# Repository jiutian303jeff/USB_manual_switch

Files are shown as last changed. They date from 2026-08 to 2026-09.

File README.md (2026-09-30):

# USB-A Physical Isolation Switch
---

## 📢 Current Update 
## (August 30, 2026)
### Overview & current update link: https://docs.google.com/document/d/1pLDk2mAq172Uoo87mN2TMu-KEBSsqmwrNO6xUET-iXo/edit?usp=drive_link

**Ver 2.0 Final Fabrication Release & Design Freeze**
* **TVS ESD Protection Integration**: Integrated an industrial-grade **SRV05-4** TVS diode array to clamp electrostatic discharge and voltage spikes during hot-plugging.
* ** D+/D-  Signal Tuning**: Executed single-track serpentine length tuning on differential signal traces to optimize USB 2.0 signal integrity.
* **100% Single-Sided Top Placement**: Re-engineered component placement, consolidating all connectors, switches, TVS ICs, and LEDs onto the Top Layer F.Cu for an improved visual aesthetic and lower-cost single-sided SMT reflow.
* **Ground Copper Pour**: Replaced thin discrete ground tracks with continuous Top and Bottom Ground Planes to minimize impedance and lower EMI.
* **Manufacturing Package**: All production Gerber files, drill files have been verified via KiCAD DRC (0 Errors) and packaged for fabrication.

---

##  Product Overview

The **USB-A Physical Isolation Switch** is an air-gapped hardware security and power management device designed in KiCAD 9.0. Unlike software-based toggles that rely on OS drivers and remain vulnerable to remote exploits, this hardware module provides a physical "hard-cut" for USB-connected peripherals. It ensures absolute data privacy, prevents unauthorized data exfiltration, and offers convenient hardware resetting without the mechanical wear of repeated plugging/unplugging.

note: content will change over time based on latest updates

---

##  Key Features

* **Air-Gapped Privacy & Security**: Physical DPDT switch physically breaks  V_{BUS}  power and  D+  data lines for 100% reliable hardware-level isolation.
* **Sub-Nanosecond ESD Protection**: Integrated **SRV05-4** TVS diode array clamps voltage transients across  V_{BUS} ,  D+ , and  D-  lines.
* **Matched Differential Pair ( 0.00\text{ mm}  Skew)**: Serpentine length tuning compensates for trace length differences caused by switch cutouts, maintaining data integrity.
* **Single-Sided SMT Layout**: Unified component layout on the top side simplifies assembly and provides a clean, professional finish.
* **Solid Grounding & EMI Reduction**: Continuous Ground Copper Pour (GND Zone) on both layers reduces ground loop impedance and improves heat dissipation.
* **Dual-LED Status Indication**:
  * 🟢 **Green LED ( ON\_GREEN )**: Active connection ( V_BUS  and data lines fully connected).
  * 🔴 **Red LED ( OFF\_RED )**: Isolated/OFF state ( V_BUS  disconnected from downstream port, routing through a  220,mega  resistor).

---

## 📁 File content

```text
.
├── final.zip                            # Complete manufacturing package (All Gerbers, Drill files etc)
├── USB-A switch overview.pdf            # Initial Ver 1.0 baseline documentation & overall project concept https://docs.google.com/document/d/1pLDk2mAq172Uoo87mN2TMu-KEBSsqmwrNO6xUET-iXo/edit?usp=drive_link
├── USB-A switch ver-xx.xx_update.pdf    # Updating report detailing new elements, technical iteration & design rationale https://docs.google.com/document/d/1X9TlPd9sVfkH2GCSMDSQgF4tiR_iDZ1_ytxDP3pgHG8/edit?usp=sharing
├── new_KiCAD_thing.kicad_pcb            # KiCAD PCB layout source file
├── new_KiCAD_thing.kicad_sch            # KiCAD schematic source file
├── PCB.png                              # High-resolution PCB Layout diagram preview
├── Schematic.png                        # High-resolution Schematic diagram preview
└── README.md                            # Project documentation
```

## 👤 Author & Acknowledgments

* **Author**: Haoyang Jiang
* **Date**: August 30, 2026
* **Designed With**: KiCAD EDA 9.0

---

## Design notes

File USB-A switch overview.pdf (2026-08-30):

# USB-A Manual Switch Ver 1.0

### A Physical USB Switch

Project Report | 2026 | Haoyang Jiang

## 1. Project Overview

The primary goal of this project was to

design and prototype a custom USB-A

Manual Power Switch. This hardware

module provides a physical "hard-cut" for

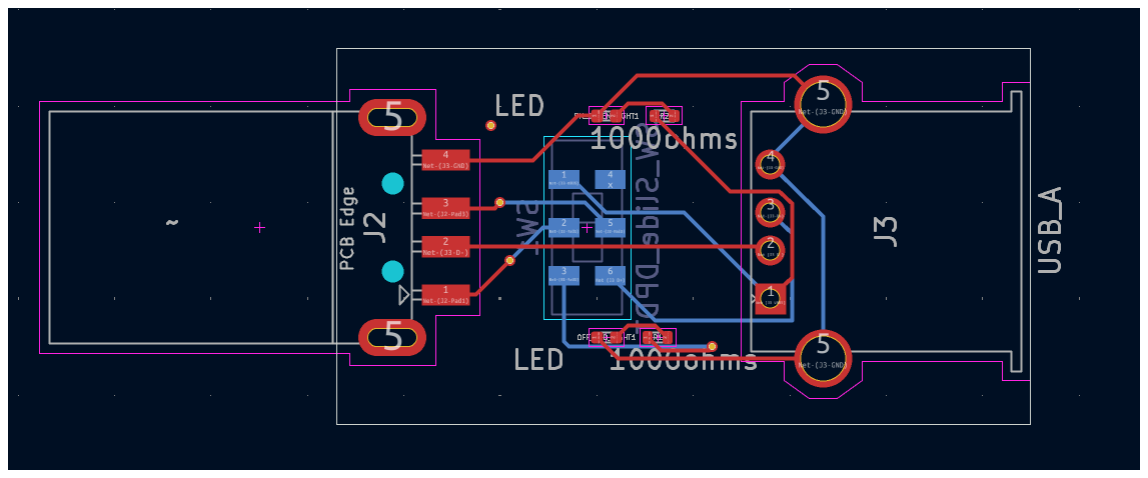
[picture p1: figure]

USB-connected peripherals, addressing the need for enhanced privacy and convenient

hardware resetting without the wear and tear of frequent plugging/unplugging.

### Technical Scope

The development process involved a full-cycle Electronic Design Automation (EDA)

workflow, encompassing:

- Schematic Capture: Designing the electrical logic and selecting appropriate components (USB

connectors, LED indicators, and slide switches).

- PCB Layout: Translating the logic into a physical 2-layer board design using KiCAD 9.0.
- Mechanical Constraint Management: Managing height interference between high-profile USB

connectors and low-profile switches.

### Key Features

- Mixed-Signal Integration: Successfully

integrated Surface Mount Device (SMD)

components for space-saving and

Through-Hole Technology (THT)

components for mechanical structural

integrity.

- Optimized 3-D Routing: Utilized multi-layer

routing strategies and via-interconnections to

achieve a compact footprint.

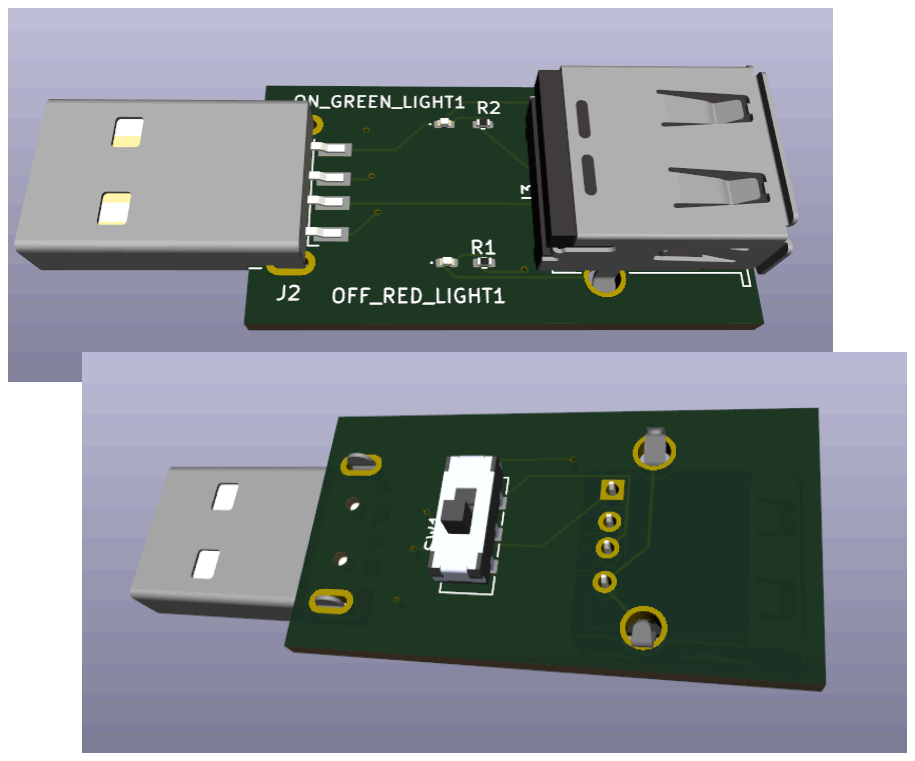
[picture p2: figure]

- Manufacturing Ready: The final design passed all Design Rule Checks (DRC), meeting

industrial standards for trace clearance, silk-screen alignment, and board edge integrity.

## 2. Social and Practical Value

### A. Absolute Security through Physical Disconnection

Unlike software-based toggles (which rely on the integrity of the Operating System and drivers), a

physical switch provides an "Air-gapped" level of security.

- Unhackable Nature: Since the switch physically breaks the VCC (5V) or Data lines, no

malware or remote exploit can bypass the hardware state. This is the only 100% reliable

method to prevent unauthorized data exfiltration or peripheral hijacking.

### B. Psychology of Control: The "Sense of Agency"

Research in human-computer interaction suggests that users feel a significantly higher sense of

agency (the feeling of being in control of one’s actions and their effects) when using mechanical

interfaces compared to digital ones.

- Visibility vs. Obscurity: A software icon can be spoofed or fail to update due to a system lag.

A physical switch provides a permanent, visible state that requires no "trust" in the

software—the user can see and feel the disconnected state.

- The "Locus of Control": Moving the privacy control from the "System" (External Locus) to

the "User's hand" (Internal Locus) reduces "techno-anxiety." Users no longer need to wonder,

"Is the light really of because the camera is of , or because the hacker disabled the LED?"

### C. Tactile Feedback and Closure (Psychological Satisfaction)

The use of a mechanical slide switch taps into the psychology of Haptic Feedback:

- Sensory Confirmation: The "click" or resistance of a physical switch provides immediate

auditory and tactile confirmation. This sensory loop creates a psychological "Sense of

Closure," delivering a level of satisfaction and "peace of mind" that a silent mouse click on a

screen cannot replicate.

- Ritualistic Security: For high-stakes environments (e.g., sensitive meetings), the act of

physically flicking a switch becomes a "security ritual" that reinforces the user’s confidence

in their environment's privacy.

## 3. Challenges and Engineering Solutions

### Challenge A: Vertical Geometric Interference

- The Problem: The standard USB-A Female connector (J3) has a significant vertical profile

(approx. 7mm). When placed on the same side as the Slide Switch (SW1), the connector's

casing physically obstructed finger access to the switch, making the device nearly impossible

to operate.

- Engineering Solution: Implemented a Bottom-Layer Component Strategy. By flipping the

switch to the Bottom Copper Layer (B.Cu) while keeping the connectors on the Top Layer

(F.Cu), I utilized the PCB substrate as a physical separator. This maximized ergonomic

accessibility without increasing the PCB's X-Y footprint.

### Challenge B: Cross-Layer Electrical Connectivity

- The Problem: Shifting the switch to the bottom layer disconnected it from the main 5V power

bus on the top layer. I needed a way to route high-current power through the board without

compromising signal integrity.

- Engineering Solution: I utilized Vias (Vertical Interconnect Access) to create "electrical

bridges."

- I routed the 5V input to a Via on the top layer, transitioned the signal to the bottom

layer to interface with the switch, and then used another Via to bring the switched

power back to the top-layer output.

- Trace Width Optimization: To handle up to 2A of current, I increased the power trace

width to 0.5mm, ensuring low resistance and preventing overheating.

### Challenge C: Mechanical Durability & Stress Management

- The Problem: USB ports are subject to frequent insertion and withdrawal forces, which can

easily snap the solder joints of Surface Mount (SMD) connectors.

- Engineering Solution: I opted for Through-Hole Technology (THT) for the USB-A

connectors. The THT pins penetrate the entire PCB and are soldered on both sides, providing superior mechanical anchorage compared to SMD pads. This ensures the device can

withstand long-term physical stress.

### Challenge D: Design Rule Constraint (DRC) Violations

- The Problem: During the final verification, the KiCAD DRC engine flagged "Silkscreen

clipped by board edge" and "Malformed board outline" errors.

- Engineering Solution: * I performed a manual audit of the Edge.Cuts layer to ensure a

perfectly closed-loop polygon.

- I resolved the silkscreen warnings by modifying the J2 footprint, trimming the

non-essential legend lines that extended beyond the manufacturing boundary. This

ensured a clean, professional finish without any "bleeding" of ink during the

fabrication process.

## 4. Technical Summary

This section summarizes the technical specifications and design standards achieved in the

final version of the PCB.

### PCB Specifications

- Board Type: Dual-layer Rigid PCB (FR-4 Substrate).
- Dimensions: Compact form factor designed for portable USB integration.
- Copper Weight: 1 oz/ft² (Standard for stable power delivery).
- Surface Finish: HASL (Hot Air Solder Leveling) with Lead-Free compatibility.

### Electrical Parameters

- Operating Voltage: 5.0V DC (Standard USB Bus Voltage).
- Current Capacity: Rated for up to 2.0A, supported by 0.5mm power traces to minimize

voltage drop and thermal buildup.

- Signal Integrity: Maintains direct data line continuity (D+/D-) for peripheral recognition

while switching the VCC line.

### Design Compliance (DRC Results)

The design was validated against industrial manufacturing constraints using the KiCAD 8.0

Design Rule Checker:

- Critical Errors: 0
- Unconnected Items: 0
- Minimum Clearance: 0.2 mm (Ensures no short circuits during fabrication).
- Minimum Trace Width: 0.25 mm (Signal) / 0.5 mm (Power).

## Schematic Overview:

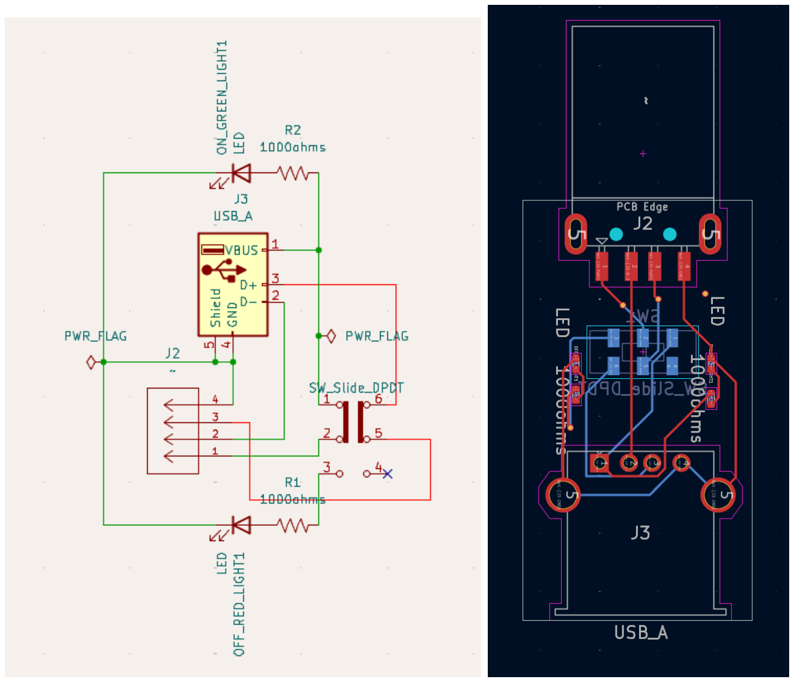
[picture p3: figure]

## 5. Relevance to Engineering Study

This project served as a practical bridge between high school theoretical physics and applied

engineering, reinforcing several core competencies required for undergraduate success:

### A. Application of Theoretical Physics

The design process required a deep understanding of Ohm’s Law and Thermal Dynamics.

Calculating the necessary trace width to support 2A of current without excessive heat

generation transformed an abstract classroom formula into a critical design constraint. This

reinforced the importance of using mathematical models to predict hardware behavior before

fabrication.

### B. Systems Thinking and Spatial Reasoning

Working in a 3D CAD environment (KiCAD) demanded advanced spatial reasoning. Solving

the interference between the USB-A housing and the switch through Bottom-Layer

Implementation taught me how to view a system as a 3D entity rather than a 2D drawing. This

aligns with the "Systems Thinking" approach central to Mechatronics and Electrical

Engineering.

### C. The Iterative Design Cycle

The transition from a "Malformed Outline" error to a "0 Error / 0 Warning" state exemplified

the Engineering Design Process (EDP). I learned that engineering is rarely about getting it

right the first time; it is about systematic debugging, interpreting technical documentation,

and iterating until the design meets all safety and manufacturing constraints.

### D. Attention to Detail and Documentation

The rigorous requirement for DRC (Design Rule Check) compliance taught me that precision

is paramount. A single 0.2mm clearance violation could lead to a short circuit and project

failure. This project cultivated a disciplined approach to technical documentation and

rule-following that is essential for professional engineering practice.

## 6. Conclusion & Future Work

This project successfully demonstrates the feasibility of a high-current, compact USB power

switch designed through advanced PCB routing techniques. By navigating complex 3-D

spatial constraints and adhering to rigorous manufacturing standards, I have developed a

hardware solution that bridges the gap between digital privacy needs and physical

ergonomics. The successful elimination of all DRC errors confirms that the design is ready

for industrial fabrication and practical deployment.

### Future Work

While the current version (v1.0) achieves its core functional goals, I intend to further iterate on the

design in the following areas:

- Enclosure Integration: I plan to export the PCB as a STEP model and utilize Fusion 360 for

collaborative mechanical design. This will involve creating a custom-fit, 3D-printed enclosure

with integrated mounting bosses and precise port cutouts.

- Smart Logic Expansion: Future iterations could incorporate a microcontroller (e.g., an

ATTiny85) to allow for timed power-offs or software-integrated logic, transitioning the

project from a manual switch to a programmable power management hub.

- Component Surface Optimization: Exploring ENIG (Electroless Nickel Immersion Gold)

surface finishing to improve long-term contact reliability and oxidation resistance for the USB

terminals.

— End of Report —

Reference

Moore, J. W. (2016). What is the sense of agency and why does it matter? Frontiers in Psychology.

Lazar, J., et al. (2017). Research Methods in Human-Computer Interaction. Morgan Kaufmann.

Rotter, J. B. (1966). Generalized expectancies for internal versus external control of reinforcement.

Schneier, B. (2018). Click Here to Kill Everybody: Security and Survival in a Hyper-connected

World. W.W. Norton & Company.

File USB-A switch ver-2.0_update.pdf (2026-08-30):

# USB-A Manual Switch Ver 2.0

### A Physical USB Switch

Project Report | 2026 | Haoyang Jiang

## Project Report Update — August 30, 2026:

Following the successful validation of the initial prototype (Ver 1.0) this revision—USB-A Manual Switch Ver 2.0—focuses on enhancing circuit protection, optimizing signal integrity for high-speed differential pairs, improving thermal/grounding performance, and streamlining mechanical assembly. While Ver 1.0 established the fundamental physical disconnection logic, Ver 2.0 upgraded the board to an industrial-grade, ESD-protected, single-sided SMT assembly design.

## New Features:

Elements | Before | After | Reason
Circuit protection | no protection | Integrated SRV05-4 TVS Diode Array | USB interfaces are prone to ESD spikes during hot-plugging. The SRV05-4 provides sub-nanosecond clamping protection on VBUS, D+, and D- lines, making the standalone capacitor redundant while significantly boosting transient protection.
Signal Integrity (D+/D-) | Uncompensated differential traces passing through switch cutouts | Equalized $D+/D-$ traces using KiCAD single-track length tuning (meanders). | Because D+ routes through the DPDT switch while D- routes directly, an imbalance

in trace length was
introduced.
Snake-style length
tuning ensures
identical electrical
length, eliminating
phase skew in USB
2.0 differential
signaling.

Component Placement Dual-side placement: USB ports & LEDs on
Top (F.Cu); Switch on
Bottom (B.Cu)

100% Single-sided
Top Placement (all
SMT/THT
components on F.Cu).

Ver 1.0 flipped the
switch to the bottom
to avoid height
interference, but this
increased assembly
complexity and
required dual-sided
SMT reflow/soldering.
Adjusting component
spacing allowed
everything to fit
cleanly on the top side
for an aesthetically
unified look and lower
fabrication cost.

Grounding Strategy Thin, discrete 0.5mm GND routing tracks.

Solid Ground Copper
Pour (Top & Bottom
Ground Planes with
stitched vias).

Discontinuous ground
tracks increase return
path impedance and
EMI radiation. A solid
ground pour lowers
ground loop
impedance, enhances
heat dissipation, and
improves ESD
immunity.

Components
Adjustment

1000ohm
current-limiting
resistors
220 ohm | Adjusted resistor
values to optimize
LED brightness for
clear visual indication
under bright ambient
lighting while
remaining within safe
current limits

## New Features Overview:

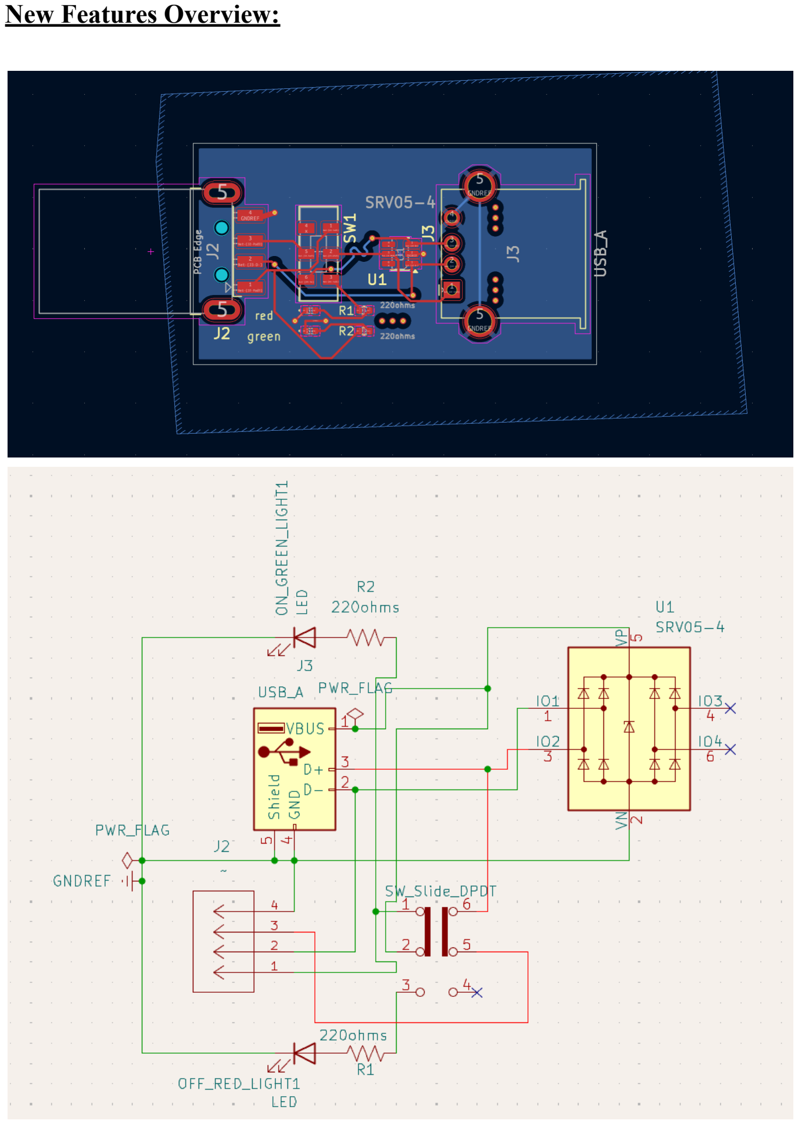
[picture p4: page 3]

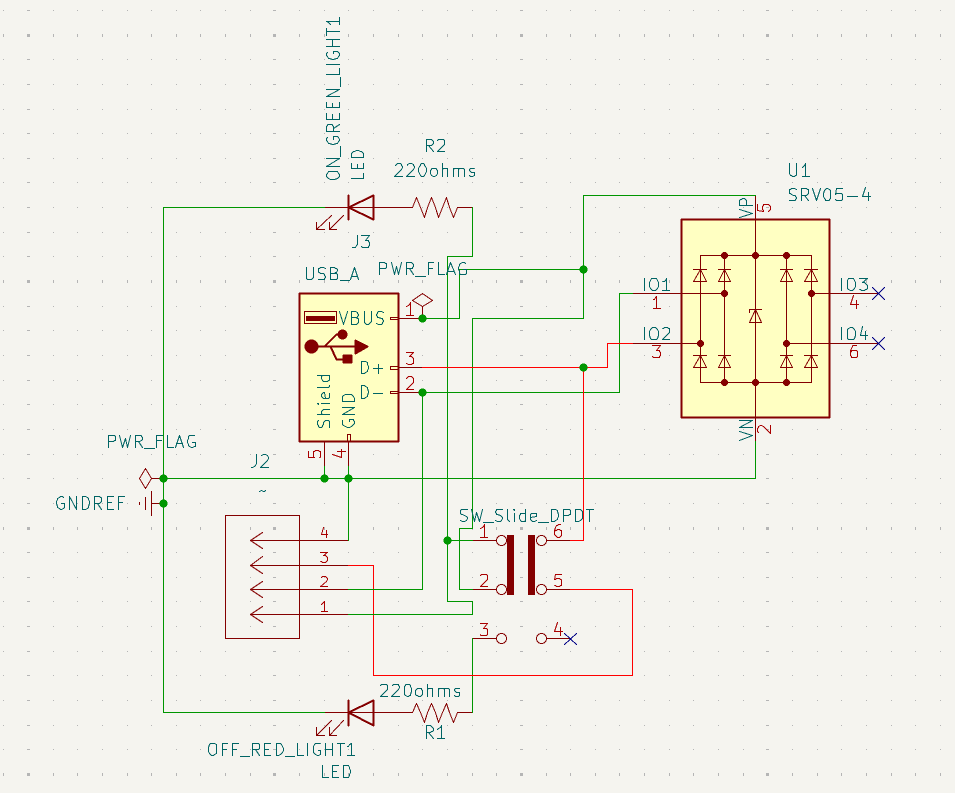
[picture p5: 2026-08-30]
Schematic.png

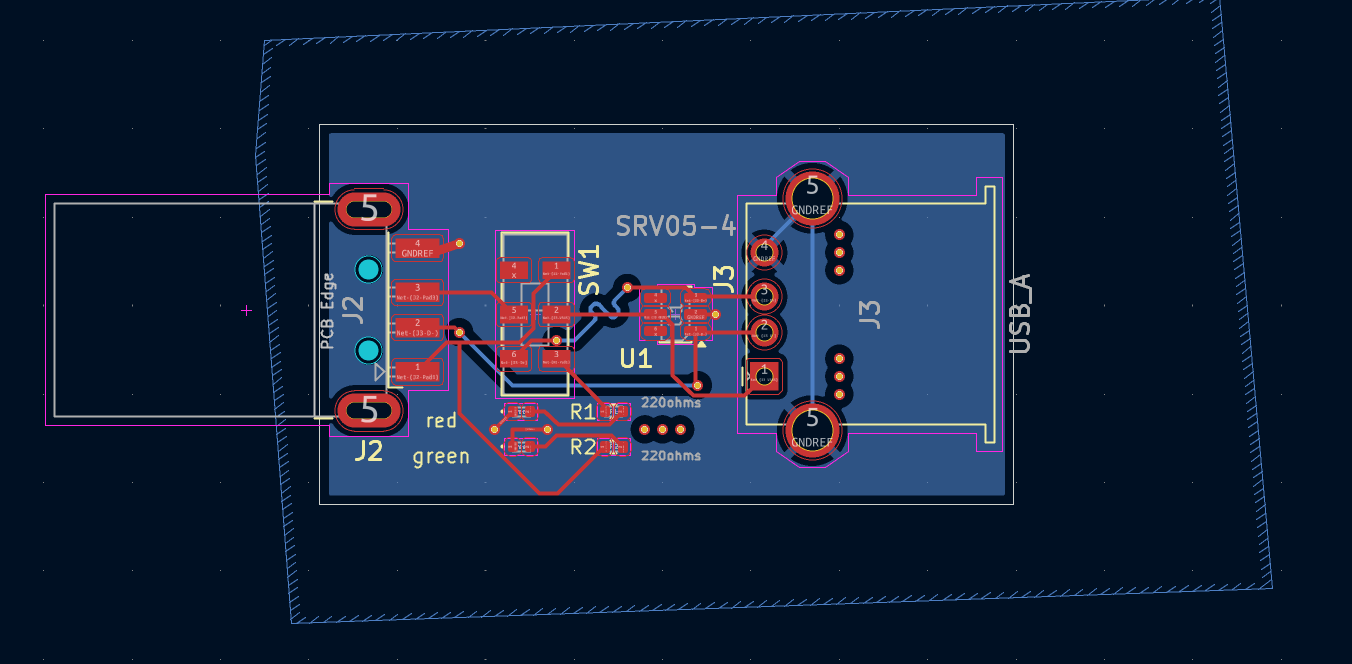
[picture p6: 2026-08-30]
PCB.png

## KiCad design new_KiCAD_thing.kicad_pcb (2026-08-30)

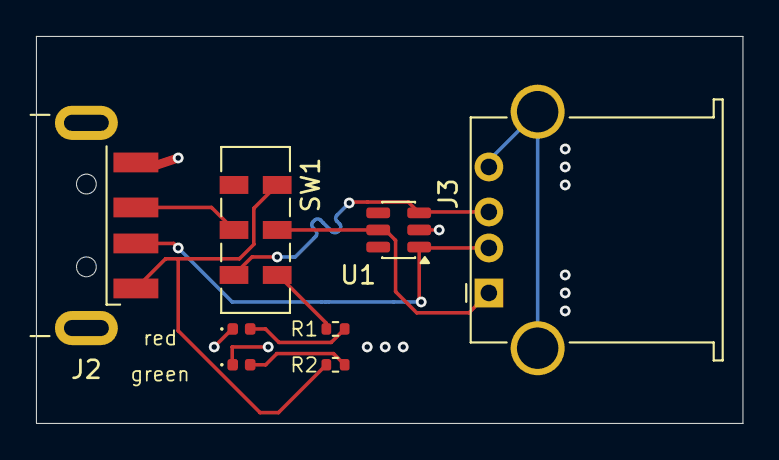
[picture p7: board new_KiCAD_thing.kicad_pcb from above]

Board: 2 copper layers, 39.2 x 21.5 mm, 8 parts (0 on the bottom side), 9 nets.

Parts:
J2: USB_A_CNCTech_1001-011-01101_Horizontal
J3: USB_A; USB_A_Stewart_SS-52100-001_Horizontal
R1, R2: 220ohms; R_0402_1005Metric
SW1: SW_Slide_DPDT; SW_DPDT_CK_JS202011JCQN
U1: SRV05-4; SOT-23-6
green: LED; LED_0402_1005Metric
red: LED; LED_0402_1005Metric

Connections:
GNDREF: J2.4, J3.4 (GND), J3.5 (Shield), U1.2 (VN), green.1 (K), red.1 (K)
unnamed: J2.1, R2.1, SW1.1 (A)
unnamed: J2.3, SW1.5 (B)
unnamed: J3.3 (D+), SW1.6 (C), U1.3 (IO2)
unnamed: J2.2, J3.2 (D-), U1.1 (IO1)
unnamed: J3.1 (VBUS), SW1.2 (B), U1.5 (VP)
unnamed: R1.2, red.2 (A)
unnamed: R2.2, green.2 (A)
unnamed: R1.1, SW1.3 (C)

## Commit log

2026-08-30 Update manufacturing package details in README
    Removed mention of 3D CAD STEP models from the manufacturing package section in the README.
2026-08-30 Remove schematics directory from README
    Removed reference to KiCAD schematic source files.
2026-08-30 Update README with links to USB-A switch documents
    Added links to Google Docs for USB-A switch documentation.
2026-08-30 Revise current update section in README
    Updated the README with current update links and details.
2026-08-30 Update README with consolidated document links
    Consolidated overview and current update links into a single line.
2026-08-30 Add PCB and Schematic preview images to README
    Added high-resolution PCB and schematic diagram previews to the documentation.
